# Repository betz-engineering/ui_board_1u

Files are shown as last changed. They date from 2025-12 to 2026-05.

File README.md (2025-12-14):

# ui_board_1u
A versatile user interface PCB, specifically designed for integration into the front-panel of a 1U height chassis.

__Featuring__

  * Rotary encoder
  * 2x RGB LEDs, brought to the front with light-pipes for mounting flexibility
  * 1x Tactile push button
  * 2.8" diagonal, 256 x 64 pixel OLED display with 16 shades (SSD1322)
  * All connected to a single 12 pin PMOD port

[__Schematic__](pics/ui_board_1u.pdf)

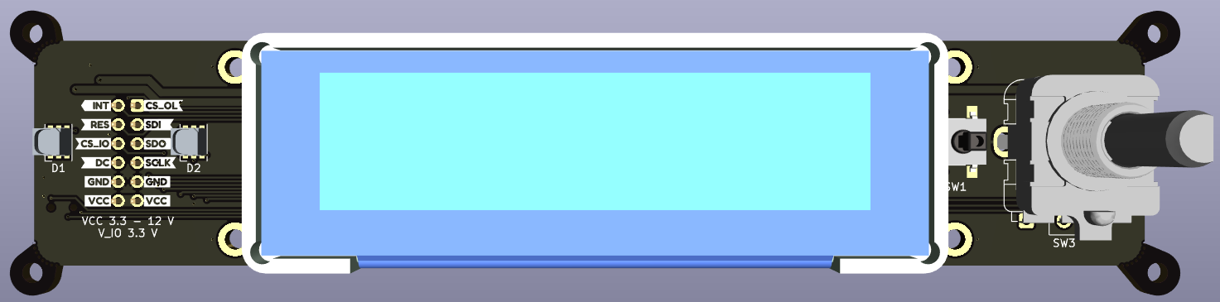
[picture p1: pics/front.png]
Front side render


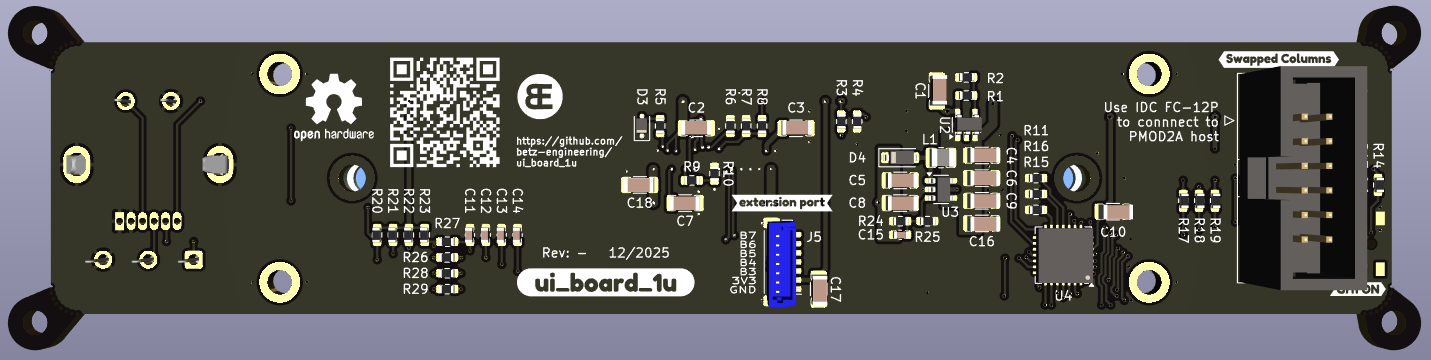
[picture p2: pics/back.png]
Back side render


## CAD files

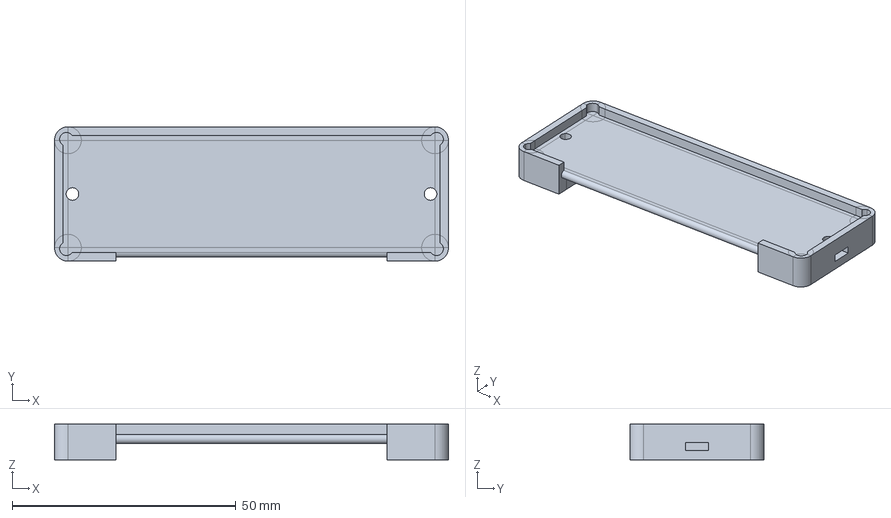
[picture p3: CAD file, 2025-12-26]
cad/step/oled_panel_frame.step
88.0 x 30.0 x 8.00 mm

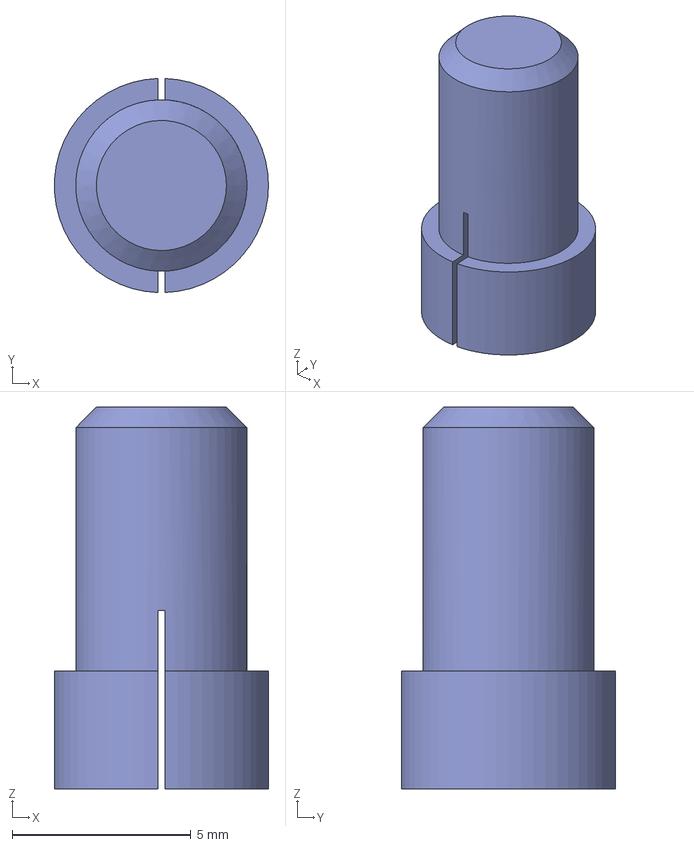
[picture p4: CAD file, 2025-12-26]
cad/step/button_cap.step
5.99 x 6.00 x 10.7 mm

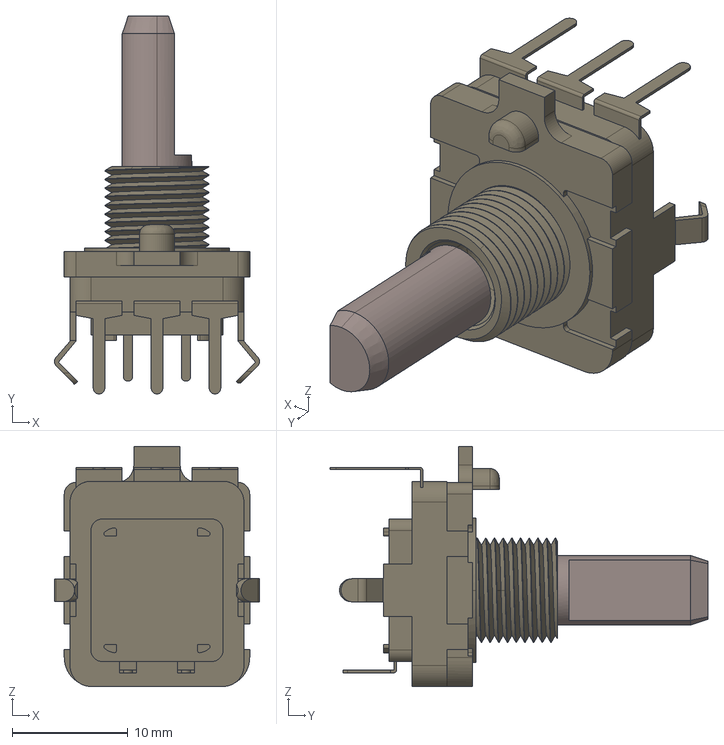
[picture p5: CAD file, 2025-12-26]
cad/step/PEC16-4X20F-SXXXX.stp
17.7 x 32.6 x 20.7 mm
PEC16-4X20F-SXXXX
PEC16-4X20F-SXXXX001

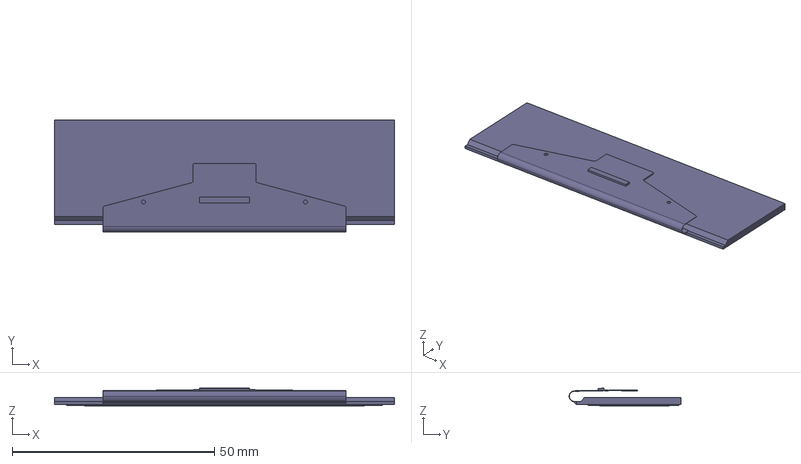
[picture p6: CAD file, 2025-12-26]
cad/step/oled_panel_2.8inch.step
84.0 x 27.6 x 4.35 mm
NHD-2.8-25664UCx008 x 2
Sketch

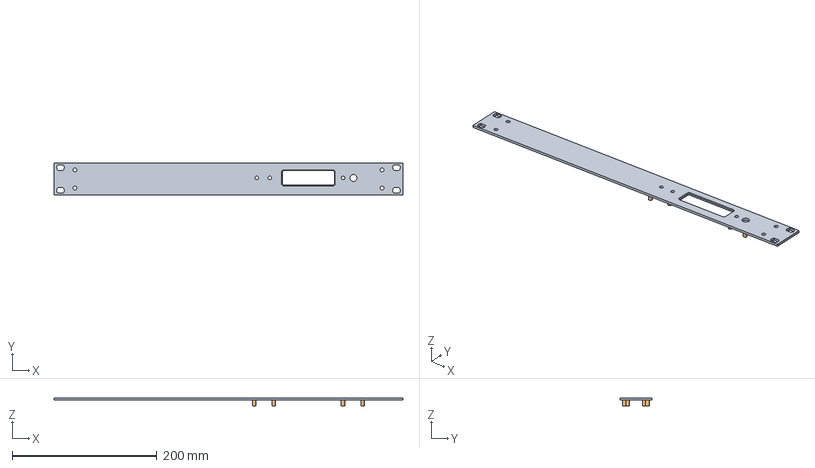
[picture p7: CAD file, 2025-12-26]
cad/step/example_panel_1U.stp
483.0 x 43.6 x 11.0 mm

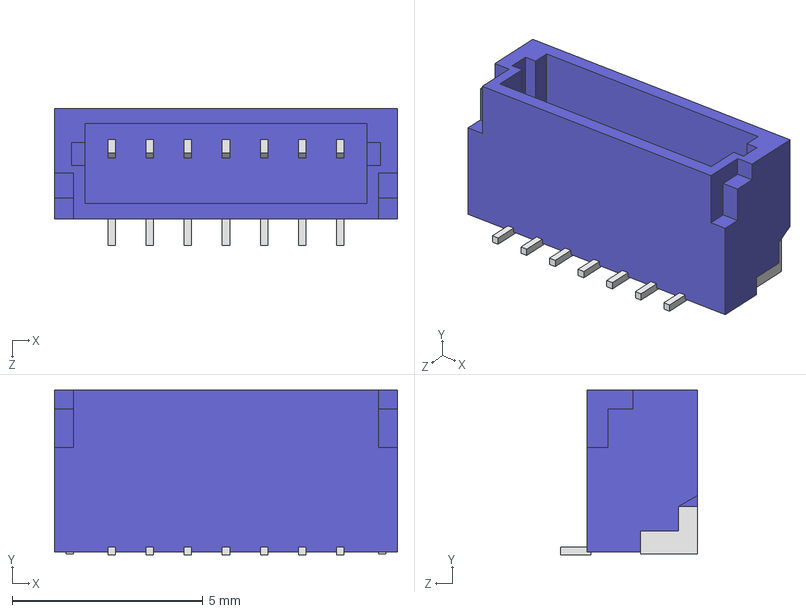
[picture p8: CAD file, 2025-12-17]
cad/step/BM07B-SRSS-TB.STEP
9.00 x 4.32 x 3.60 mm

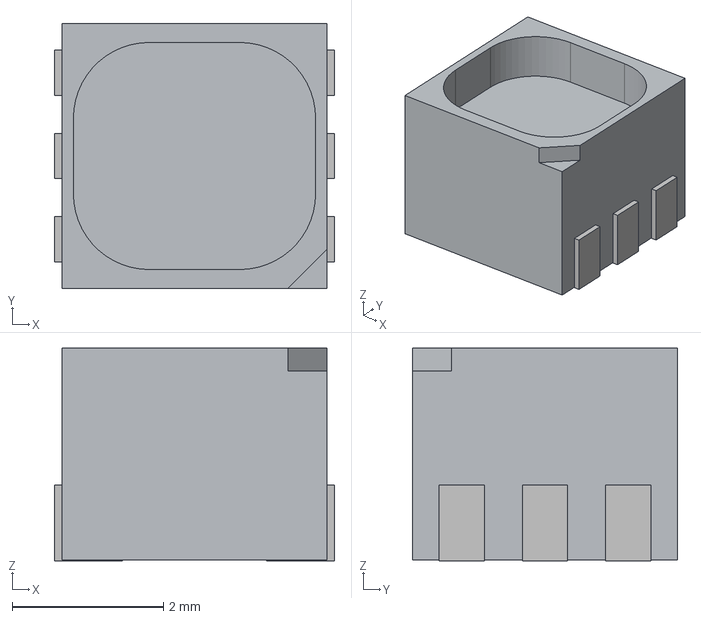
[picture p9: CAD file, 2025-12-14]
cad/step/RS-3535MWAR.step
3.70 x 3.50 x 2.81 mm

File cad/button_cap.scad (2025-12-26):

$fn = $preview ? 30 : 200;

include <helpers.scad>

gap = 0.2;

w_head = 2.4 + gap;
w_clip = w_head - 0.5;

h_clip = 1.0;  // height of the hook shaped clip
h_head = 1.8 + gap;  // height of the cube head of the button
h_stamp = h_clip + h_head;  // total height of the negative area

h_button = 8 + 7; // total height of the button measured from the _PCB_
h_cap = h_stamp + h_button - 7.3;
echo(h_cap);

module half_stamp() {
	polygon(points=[
		[0, 0],
		[-w_head / 2, 0],
		[-w_clip / 2, h_clip],
		[-w_head / 2, h_clip],
		[-w_head / 2, h_stamp],
		[0, h_stamp],
	]);
}

// half_stamp();

module stamp() {
	translate([0, w_head / 2, 0])
		rotate([90, 0, 0])
			linear_extrude(w_head)
				union() {
					half_stamp();
					mirror([1, 0, 0]) half_stamp();
				}
}

module cap(){
	difference() {
		union() {
			// Outer diameter of the cap (which needs to fit in the 5 mm hole of the FP)
			cylinder(h=h_cap, d=5 - gap);
			// larger diameter for the inside part
			cylinder(h=h_stamp + 8 - 7.3 - 2 * gap, d=6);
		}
		stamp();
		// the slot
		cube(size=[gap, 10, 10], center=true);
		// chamfer the edges on the top
		translate([0, 0, h_cap - 5.25])
			cone();
	}
}

module cone()
	rotate_extrude()
		translate([5 * sqrt(2), 0, 0])
			rotate([0, 0, 45])
				square([10, 10]);


// simulate the switch head
// translate([0, 0, 7.3 - 1.8])
// 	cube_(size=[2.4, 2.4, 1.8]);

echo("button z", -h_stamp + 7.3 + gap / 2);

intersection() {
	translate([0, 0, -h_stamp + 7.3 + gap / 2])
		!cap();
	translate([0, 50, 0])
		cube(size=[100, 100, 100], center=true);
}

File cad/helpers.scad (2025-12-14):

// centered on XY only
module cube_(size=[1, 1, 1])
	translate([-size[0] / 2, -size[1] / 2, 0])
		cube(size);

// centered on XY only
module roundedcubez(size = [1, 1, 1], radius = 0.5) {
	linear_extrude(height=size[2]) {
		square([size[0] - 2 * radius, size[1]], center=true);
		square([size[0], size[1] - 2 * radius], center=true);
		for (i=[-1, 1])
			for (j=[-1, 1])
				translate([i * (size[0] / 2 - radius), j * (size[1] / 2 - radius), 0])
					circle(r = radius);
	}
}

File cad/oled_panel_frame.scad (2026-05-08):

$fn = $preview ? 30 : 200;

include <helpers.scad>

w_panel = 84;
w_flex = 60;
h_panel = 25.8;
t_panel = 2.0;


shell_thickness = 2;

// space (wiggle room) between panel and frame around it
gap = 0.3;

// How far the bottom of the panel is lifted from the carrier PCB
h_offset = 5.7;
echo("h_offset: ", h_offset);

// Total height of the part
h_total = h_offset + t_panel + gap;
echo("h_total: ", h_total);

// The rounded lip part
d_lip = 2;
y_lip = 0;


module panel() {
	color("grey")
		translate([0, 1, (t_panel - 0.75) / 2])
			cube(size=[w_panel, h_panel - 2, t_panel - 0.75], center=true);
	color("lightgrey")
		translate([0, 0, t_panel - 0.75 / 2])
			cube(size=[w_panel, h_panel, 0.75], center=true);
	translate([0, -10 - h_panel / 2, 1.20])
		cube(size=[w_flex, 25, 0.1], center=true);
}


module oled_frame() {
	difference() {
		roundedcubez(size=[w_panel + shell_thickness * 2, 30, h_total], radius=3);

		// pocket for the display
		translate([0, 0, h_offset])
			cube_(size=[w_panel + gap, h_panel + gap, 10]);

		// Opening for the flex
		// remove the lip to shape it better
		translate([0, -10 - (h_panel + gap) / 2 - y_lip, 0])
			cube_(size=[w_flex + 2 * gap, 20, 10]);

		// Clear out the top
		translate([0, -25, h_offset])
			cube_(size=[w_flex + 2 * gap, 50, 10]);

		// Clear out the bottom
		cube(size=[w_flex + 2 * gap, 100, (h_offset - d_lip) * 2], center=true);

		// slots for M2.5 square nuts
		for (i=[-1, 1]) {
			translate([40 * i, 0, 3]) {
				translate([2 * i, 0, 0]){
					cube(size=[10, 5.1, 1.6], center=true);
				}
				translate([0, 0, -1])
					cylinder(h=10, d=2.8, center=true);
			}

			// Dog bones
			for (j=[-1, 1])
				translate([i * ((w_panel + gap) / 2 - 0.8), j * ((h_panel + gap) / 2 - 0.8), 5 + h_offset])
					cylinder(h=10, d=3, center=true);
		}
	}

	// The rounded lip
	translate([0, -(h_panel + gap) / 2 - y_lip, -d_lip/2 + h_offset]) {
		rotate([0, 90, 0])
			cylinder(h=w_flex + 2 * gap, d=d_lip, center=true);
	}

	// Square nut retainer
	for (i=[-1, 1])
		for (j=[-1, 1])
			translate([43.3 * i, j * 1.5, 3.88])
				rotate([0, -i * 15, 0])
					cube(size=[1.25, 0.6, 0.5], center=true);
}

// translate([0, 0, h_offset + gap])
// 	panel();

intersection() {
	union() {
		!oled_frame();
		// Square nut
		translate([40, 0, 2])
			cube_(size=[5.0, 5.0, 1.6]);
		// // Screw
		translate([40, 0, -1.6])
			cylinder(h=6, d=2.5);
	}
	// translate([0, 50, 0])
	// 	cube(size=[100, 100, 100], center=true);
}

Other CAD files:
cad/RS-3535MWAR.scad

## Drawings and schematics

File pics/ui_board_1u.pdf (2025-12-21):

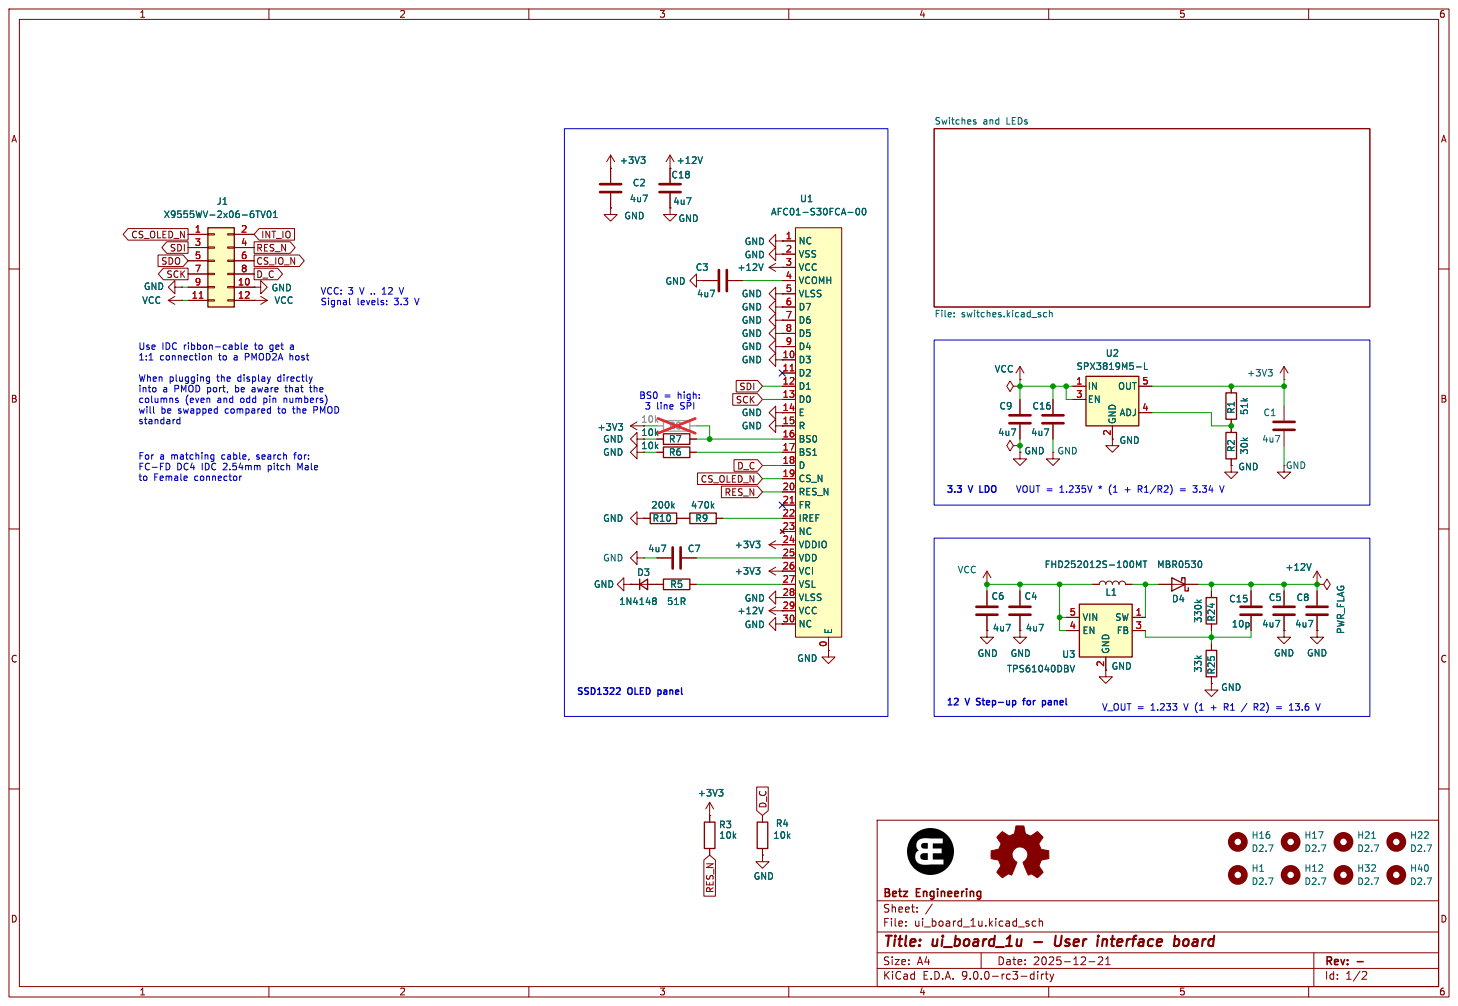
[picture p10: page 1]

10k GND GND GND GND GND GND GND GND

into a PMOD port, be aware that the

Id: 1/2 Title: ui_board_1u - User interface board

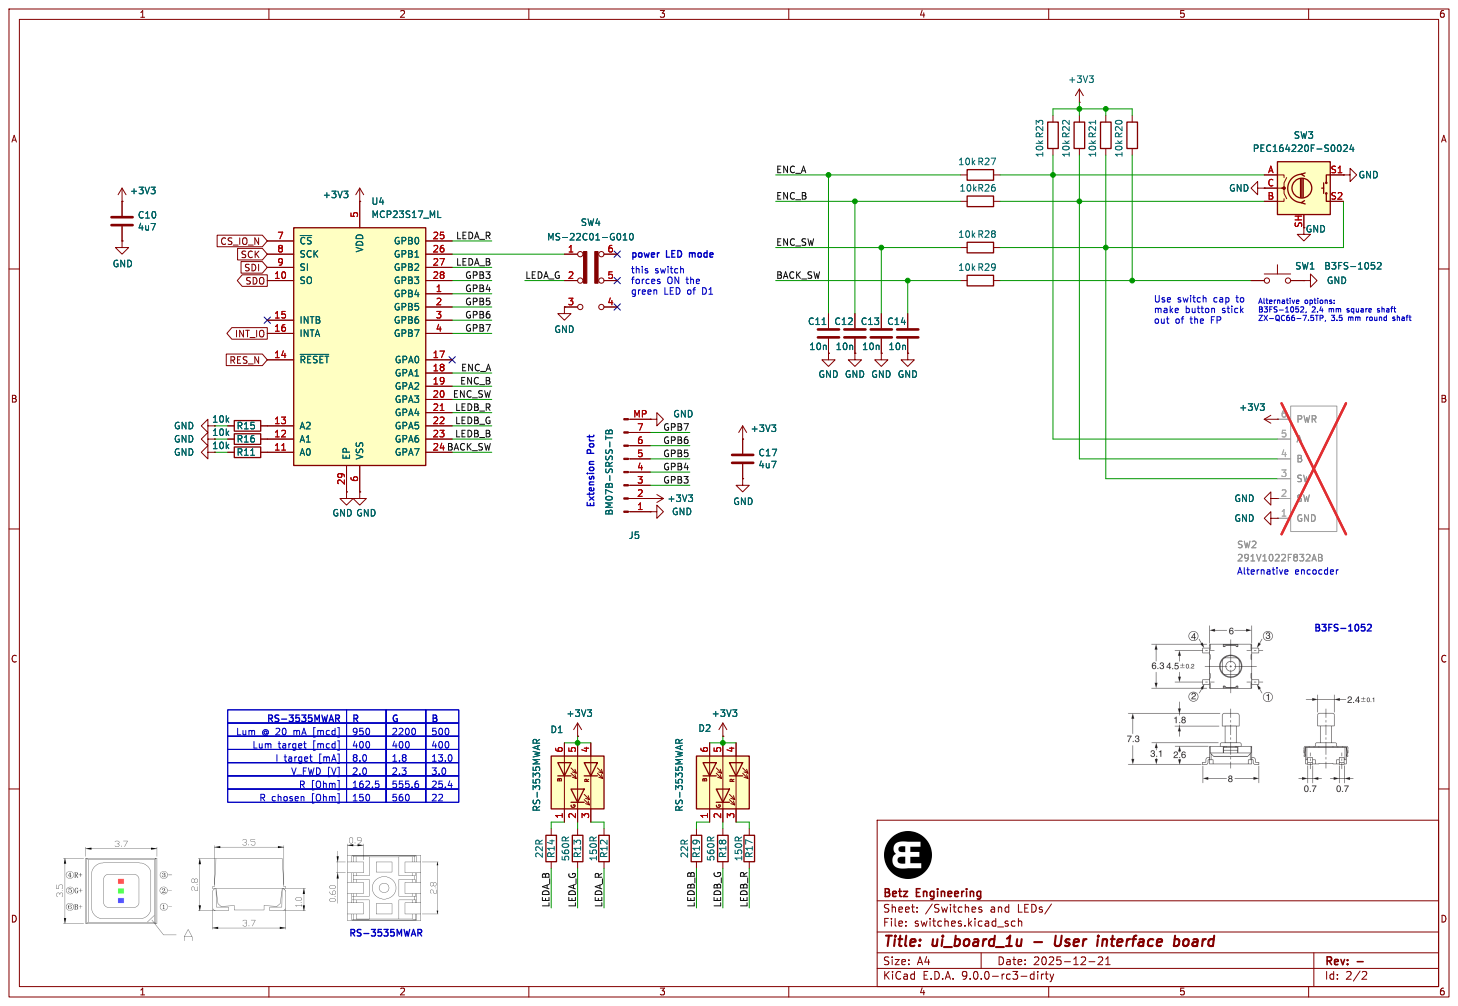
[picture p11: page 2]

6 GPB0 25 GPB1 26 GPB2 27 GPB3 28 GPB4 1 GPB5 2 GPB6 3 GPB7 4 GPA0 17 GPA1 18 GPA2 19 GPA3 20 GPA4 21 GPA5 22 GPA6 23 GPA7 24 GND GND
power LED mode Extension Port RS-3535MWAR

Id: 2/2 Title: ui_board_1u - User interface board

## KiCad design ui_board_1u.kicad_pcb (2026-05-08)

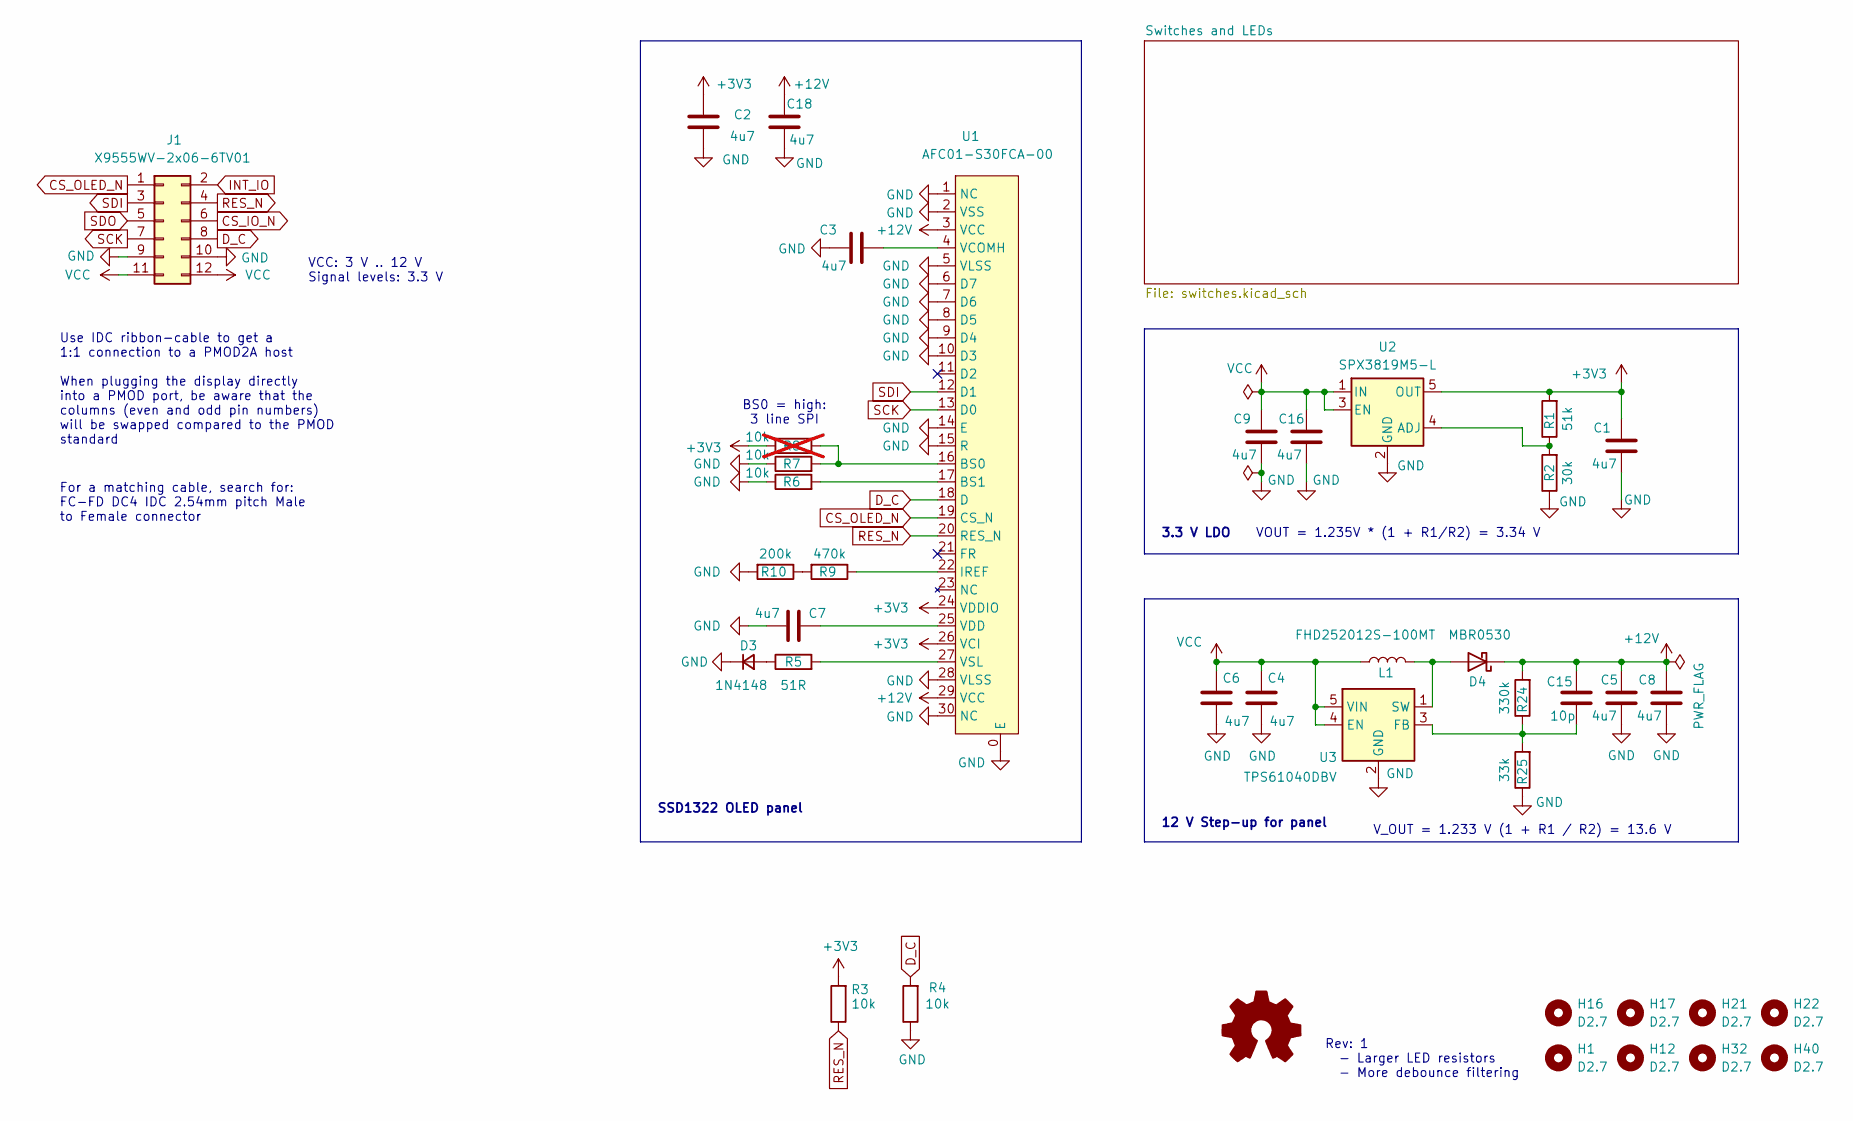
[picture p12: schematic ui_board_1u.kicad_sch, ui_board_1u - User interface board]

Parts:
C1, C2, C3, C4, C5, C6, C7, C8, C9, C16, C18: 4u7; C_1206_3216Metric
C15: 10p; C_0603_1608Metric
D3: 1N4148; D_SOD-323F
D4: MBR0530; D_SOD-123
H1, H12, H32, H40: D2.7; MountingHole_2.7mm_M2.5_ISO7380
H16, H17, H21, H22: D2.7; MountingHole_2.7mm_M2.5_ISO7380_Pad
J1: X9555WV-2x06-6TV01; IDC-Header_2x06_P2.54mm_Vertical
L1: FHD252012S-100MT; L_1008_2520Metric
R1: 51k; R_0603_1608Metric
R2: 30k; R_0603_1608Metric
R3, R4, R6, R7: 10k; R_0603_1608Metric
R5: 51R; R_0603_1608Metric
R8: 10k; R_0603_1608Metric; not fitted
R9: 470k; R_0603_1608Metric
R10: 200k; R_0603_1608Metric
R24: 330k; R_0603_1608Metric
R25: 33k; R_0603_1608Metric
U1: AFC01-S30FCA-00; oled_frame_2.8
U2: SPX3819M5-L; SOT-23-5; LCSC Part # C9056
U3: TPS61040DBV; SOT-23-5

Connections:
+3V3: C1.1, C2.1, R1.2, R3.2, R8.1, U1.24 (VDDIO), U1.26 (VCI), U2.5 (OUT); also elsewhere on the board
+12V: C5.1, C8.1, C15.1, C18.1, D4.1 (K), R24.2, U1.3 (VCC), U1.29 (VCC)
CS_IO_N: J1.6; also elsewhere on the board
CS_OLED_N: J1.1, U1.19 (CS_N)
D_C: J1.8, R4.2, U1.18 (D)
GND: C1.2, C2.2, C3.2, C4.2, C5.2, C6.2, C7.2, C8.2, C9.2, C16.2, C18.2, D3.1 (K), J1.9, J1.10, R2.1, R4.1, R6.1, R7.1, R10.2, R25.1, U1.0 (E), U1.1 (NC), U1.2 (VSS), U1.5 (VLSS), U1.6 (D7), U1.7 (D6), U1.8 (D5), U1.9 (D4), U1.10 (D3), U1.14 (E), U1.15 (R), U1.28 (VLSS), U1.30 (NC), U2.2 (GND), U3.2 (GND); also elsewhere on the board
INT_IO: J1.2; also elsewhere on the board
unnamed: D3.2 (A), R5.1
unnamed: D4.2 (A), L1.2, U3.1 (SW)
unnamed: R9.2, R10.1
unnamed: R7.2, R8.2, U1.16 (BS0)
unnamed: R6.2, U1.17 (BS1)
unnamed: R9.1, U1.22 (IREF)
unnamed: C3.1, U1.4 (VCOMH)
unnamed: C7.1, U1.25 (VDD)
unnamed: R5.2, U1.27 (VSL)
unnamed: R1.1, R2.2, U2.4 (ADJ)
unnamed: C15.2, R24.1, R25.2, U3.3 (FB)
RES_N: J1.4, R3.1, U1.20 (RES_N); also elsewhere on the board
SCK: J1.7, U1.13 (D0); also elsewhere on the board
SDI: J1.3, U1.12 (D1); also elsewhere on the board
SDO: J1.5; also elsewhere on the board
VCC: C4.1, C6.1, C9.1, C16.1, J1.11, J1.12, L1.1, U2.1 (IN), U2.3 (EN), U3.4 (EN), U3.5 (VIN)

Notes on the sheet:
12 V Step-up for panel
V_OUT = 1.233 V (1 + R1 / R2) = 13.6 V
Rev: 1 - Larger LED resistors - More debounce filtering
3.3 V LDO
Use IDC ribbon-cable to get a 1:1 connection to a PMOD2A host When plugging the display directly into a PMOD port, be aware that the columns (even and odd pin numbers) will be swapped compared to the PMOD standard
SSD1322 OLED panel
For a matching cable, search for: FC-FD DC4 IDC 2.54mm pitch Male to Female connector
BS0 = high: 3 line SPI
VOUT = 1.235V * (1 + R1/R2) = 3.34 V
VCC: 3 V .. 12 V Signal levels: 3.3 V

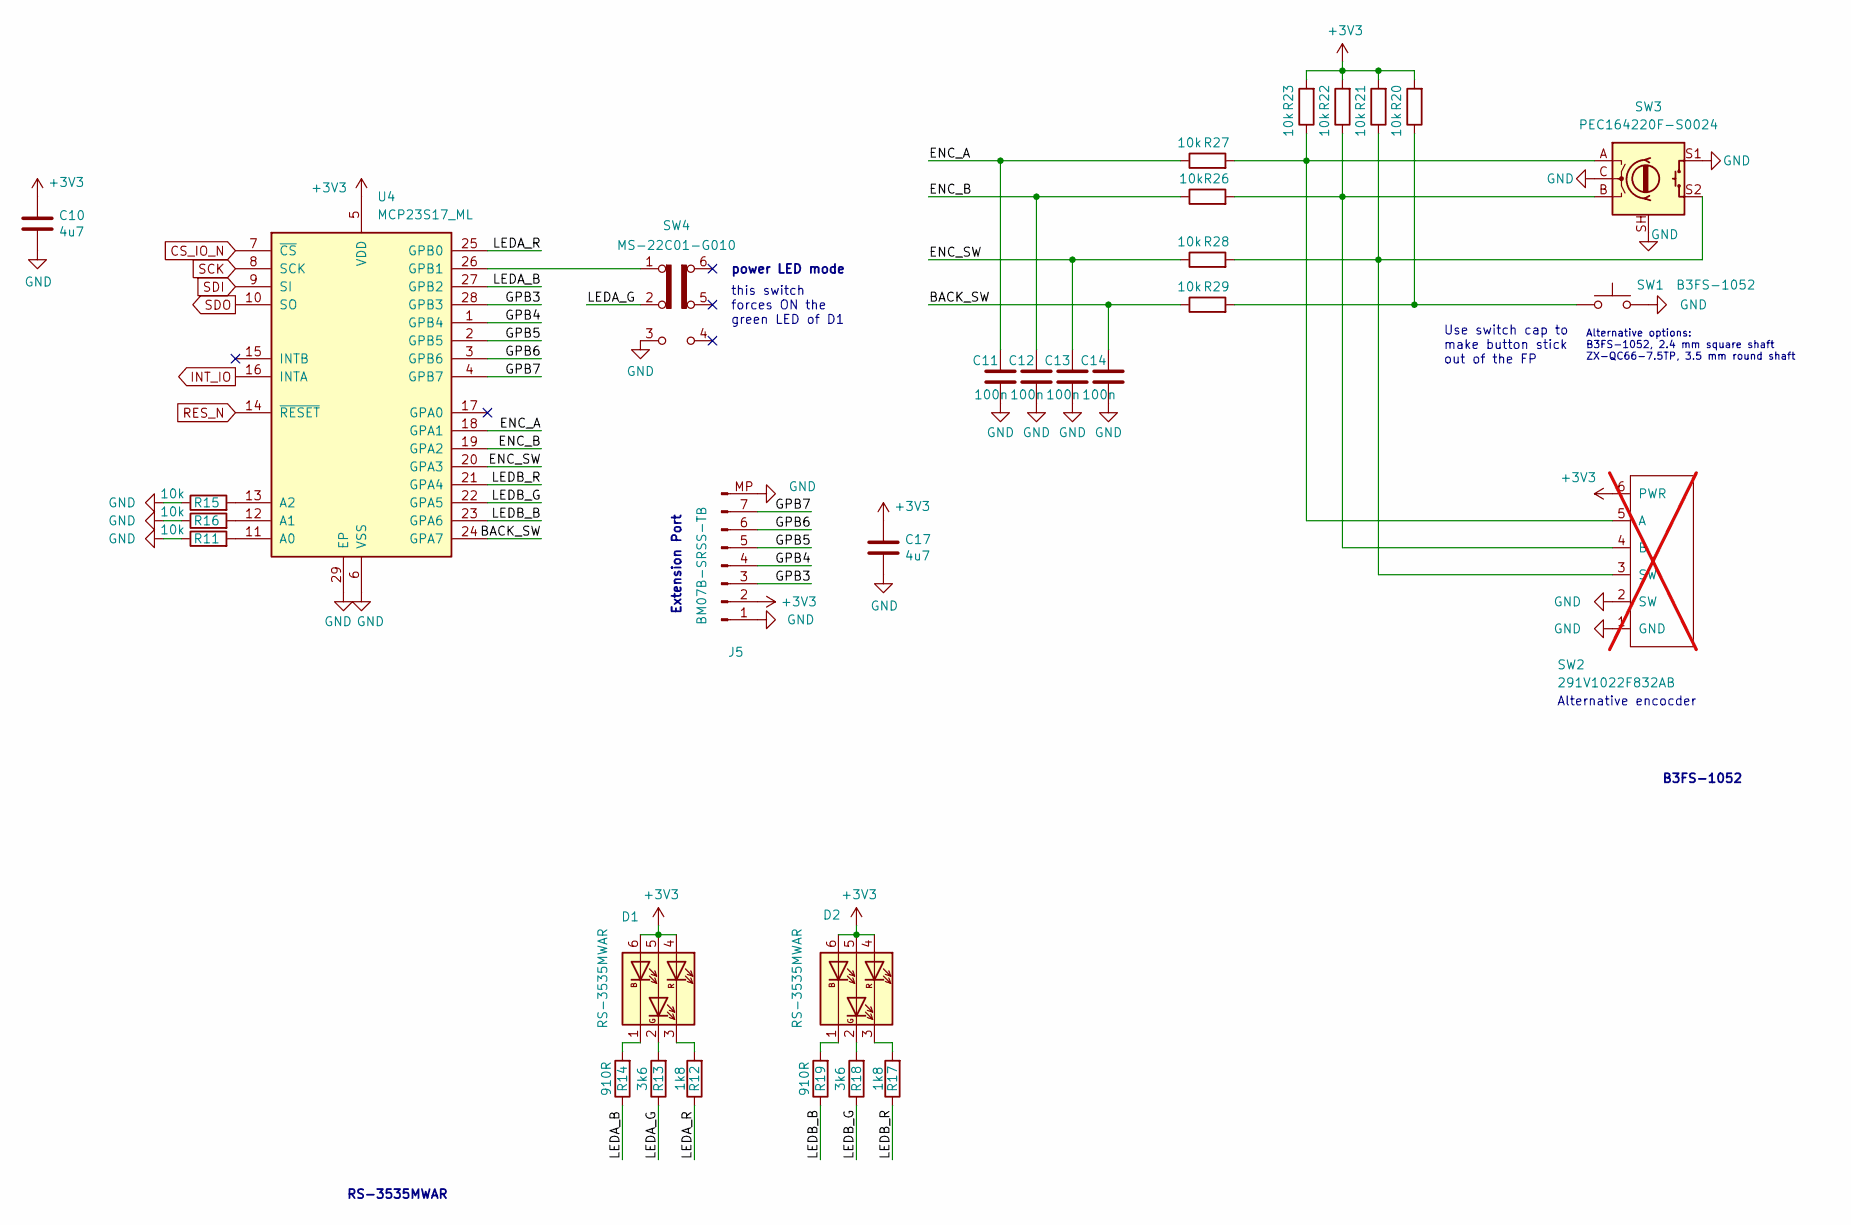
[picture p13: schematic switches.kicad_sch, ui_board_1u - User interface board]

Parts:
C10, C17: 4u7; C_1206_3216Metric
C11, C12, C13, C14: 100n; C_0603_1608Metric
D1, D2: RS-3535MWAR; LED_RGB_PLCC-6
J5: BM07B-SRSS-TB; JST_SH_BM07B-SRSS-TB_1x07-1MP_P1.00mm_Vertical; LCSC Part # C160393
R11, R15, R16, R20, R21, R22, R23, R26, R27, R28, R29: 10k; R_0603_1608Metric
R12, R17: 1k8; R_0603_1608Metric
R13, R18: 3k6; R_0603_1608Metric
R14, R19: 910R; R_0603_1608Metric
SW1: B3FS-1052; SW_SPST_Omron_B3FS-105xP
SW2: 291V1022F832AB; 291V1; digikey CT3044-ND; not fitted
SW3: PEC164220F-S0024; RotaryEncoder_Bourns_Vertical_PEC16-4xxxF-Sxxxx
SW4: MS-22C01-G010; MS-22C01
U4: MCP23S17_ML; QFN-28-1EP_6x6mm_P0.65mm_EP4.25x4.25mm

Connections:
+3V3: C10.1, C17.1, D1.4 (AR), D1.5 (AG), D1.6 (AB), D2.4 (AR), D2.5 (AG), D2.6 (AB), J5.2, R20.2, R21.2, R22.2, R23.2, SW2.6 (PWR), U4.5 (VDD); also elsewhere on the board
/Switches and LEDs/BACK_SW: C14.1, R29.1, U4.24 (GPA7)
/Switches and LEDs/ENC_A: C11.1, R27.1, U4.18 (GPA1)
/Switches and LEDs/ENC_B: C12.1, R26.1, U4.19 (GPA2)
/Switches and LEDs/ENC_SW: C13.1, R28.1, U4.20 (GPA3)
/Switches and LEDs/GPB3: J5.3, U4.28 (GPB3)
/Switches and LEDs/GPB4: J5.4, U4.1 (GPB4)
/Switches and LEDs/GPB5: J5.5, U4.2 (GPB5)
/Switches and LEDs/GPB6: J5.6, U4.3 (GPB6)
/Switches and LEDs/GPB7: J5.7, U4.4 (GPB7)
/Switches and LEDs/LEDA_B: R14.1, U4.27 (GPB2)
/Switches and LEDs/LEDA_G: R13.1, SW4.2 (B)
/Switches and LEDs/LEDA_R: R12.1, U4.25 (GPB0)
/Switches and LEDs/LEDB_B: R19.1, U4.23 (GPA6)
/Switches and LEDs/LEDB_G: R18.1, U4.22 (GPA5)
/Switches and LEDs/LEDB_R: R17.1, U4.21 (GPA4)
CS_IO_N: U4.7 (~CS); also elsewhere on the board
GND: C10.2, C11.2, C12.2, C13.2, C14.2, C17.2, J5.1, J5.MP, R11.1, R15.1, R16.1, SW1.2, SW2.1 (GND), SW2.2 (SW), SW3.C, SW3.S1, SW3.SH, SW4.3 (C), U4.6 (VSS), U4.29 (EP); also elsewhere on the board
INT_IO: U4.16 (INTA); also elsewhere on the board
unnamed: D1.1 (KB), R14.2
unnamed: D1.2 (KG), R13.2
unnamed: D1.3 (KR), R12.2
unnamed: D2.1 (KB), R19.2
unnamed: D2.2 (KG), R18.2
unnamed: D2.3 (KR), R17.2
unnamed: R20.1, R29.2, SW1.1
unnamed: R21.1, R28.2, SW2.3 (SW), SW3.S2
unnamed: R23.1, R27.2, SW2.5 (A), SW3.A
unnamed: R22.1, R26.2, SW2.4 (B), SW3.B
unnamed: R11.2, U4.11 (A0)
unnamed: R16.2, U4.12 (A1)
unnamed: R15.2, U4.13 (A2)
unnamed: SW4.1 (A), U4.26 (GPB1)
RES_N: U4.14 (~RESET); also elsewhere on the board
SCK: U4.8 (SCK); also elsewhere on the board
SDI: U4.9 (SI); also elsewhere on the board
SDO: U4.10 (SO); also elsewhere on the board

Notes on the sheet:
B3FS-1052
RS-3535MWAR
Extension Port
this switch forces ON the green LED of D1
Alternative options: B3FS-1052, 2.4 mm square shaft ZX-QC66-7.5TP, 3.5 mm round shaft
Use switch cap to make button stick out of the FP
power LED mode
Alternative encocder

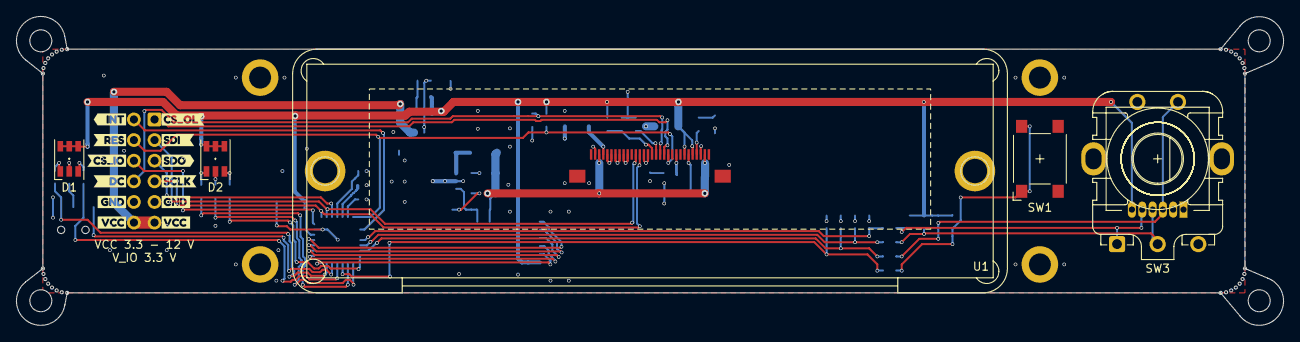
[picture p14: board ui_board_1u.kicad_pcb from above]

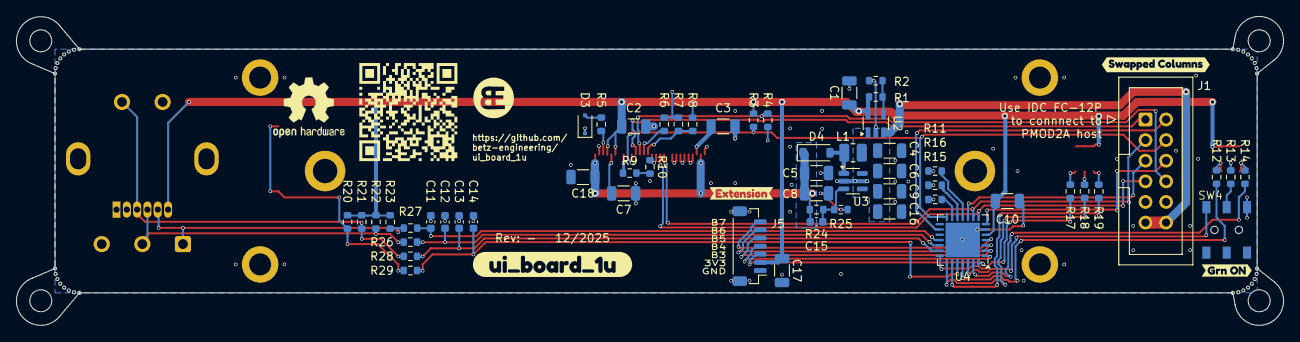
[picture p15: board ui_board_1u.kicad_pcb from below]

Board: 2 copper layers, 156.0 x 38.0 mm, 121 parts (63 on the bottom side), 52 nets.

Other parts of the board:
G0, G1: LOGO
G2: OSHW-Logo2_9.8x8mm_SilkScreen
H2, H3, H4, H5, H6, H7, H8, H9, H10, H11, H13, H14, H15, H18, H19, H20, H23, H24, H25, H26, H27, H28, H29, H30, H31, H33, H34, H35, H36, H37, H38, H39: mouse_bite
kibuzzard-1: G***; kibuzzard-693D4C30
kibuzzard-2: G***; kibuzzard-6940589C
kibuzzard-3: G***; kibuzzard-693D4C36
kibuzzard-4: G***; kibuzzard-69405870
kibuzzard-5: G***; kibuzzard-69405890
kibuzzard-6: G***; kibuzzard-6940587B
kibuzzard-7: G***; kibuzzard-693D4C42
kibuzzard-8: G***; kibuzzard-693D4BEE
kibuzzard-9: G***; kibuzzard-693D4C48
kibuzzard-10: G***; kibuzzard-693D4BE6
kibuzzard-11: G***; kibuzzard-693D4C4F
kibuzzard-12: G***; kibuzzard-693D4BDF
kibuzzard-13: G***; kibuzzard-693D4AF8
kibuzzard-14: G***; kibuzzard-693EBA51
kibuzzard-15: G***; kibuzzard-693D4DAF
kibuzzard-69483936: G***; kibuzzard-69483936

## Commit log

2025-12-14 fix 3D models
    [PEC16-4X20F-SXXXX.stp, RS-3535MWAR.step, example_front_panel_2u.step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]
2025-12-14 add QR code to silkscreen, add render images
    [ui_board_1u.kicad_pcb]
2025-12-14 optimize component values for easier production
    [switches.kicad_sch, ui_board_1u.kicad_pcb, ui_board_1u.kicad_sch]
2025-12-14 add Schematic .pdf
    [switches.kicad_sch]
2025-12-14 update Schematic sheet
    [switches.kicad_sch, ui_board_1u.kicad_sch]
2025-12-14 oled_panel_frame.scad: remove redundant code
    [oled_panel_frame.scad]
2025-12-15 rename POCI and PICO signals to SDO and SDI
    according to the OSHWA recommendation
    https://oshwa.org/resources/a-resolution-to-redefine-spi-signal-names/
    [switches.kicad_sch, ui_board_1u.kicad_pcb, ui_board_1u.kicad_sch]
2025-12-15 fix / ignore all remaining DRC errors
    [ui_board_1u.kicad_pcb]
2025-12-15 geographical re-annotate
    [switches.kicad_sch, ui_board_1u.kicad_pcb, ui_board_1u.kicad_sch]
2025-12-15 update schematic .pdf and pictures
    [ui_board_1u.kicad_pcb]
2025-12-17 review OLED pinout, add 2 GND pins
    [switches.kicad_sch, ui_board_1u.kicad_pcb, ui_board_1u.kicad_sch]
2025-12-17 add extension board connector
    [BM07B-SRSS-TB.STEP, switches.kicad_sch, ui_board_1u.kicad_pcb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]
2025-12-17 fix typo in schematic
    [switches.kicad_sch, ui_board_1u.kicad_sch]
2025-12-17 fix some more typos in the schematic
    [switches.kicad_sch, ui_board_1u.kicad_sch]
2025-12-21 add button cap for Omron button
    [button_cap.scad, oled_panel_frame.scad]
2025-12-21 Make button cap longer. Update 3D models
    [button_cap.scad, button_cap.step, oled_panel_frame.scad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]
2025-12-21 fine tune ext. con position and silk screen
    rev - ready to order
    [switches.kicad_sch, ui_board_1u.kicad_pcb, ui_board_1u.kicad_sch]
2025-12-23 add drawing for front-panel cut-outs in User.Comments and Eco1 layers
    [ui_board_1u.kicad_pcb]
2025-12-23 button-cap: change outer diameter from 5.0 to 4.6 mm
    [button_cap.scad]
2025-12-26 cutout drawing: update, snap to grid
    also add exmaple front panel designer file
    [example_panel_1U.stp, ui_board_1u.kicad_pcb]
2025-12-26 update most of the .step files
    * button_cap and oled_frame: update ot the final dimensions
    * oled_panel: add color to the active area
    * add example front-panel .step
    [PEC16-4X20F-SXXXX.stp, button_cap.scad, button_cap.step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]
2025-12-26 remove unused 2U example panel
    [example_front_panel_2u.step]
2025-12-27 move step file to website
    [ui_board_1u.step]
2026-05-08 oled_panel_frame: add square nut retainer
    [oled_panel_frame.scad]
2026-05-08 rev1, port to kicad 10
    * revise LED resistor values. They were much to bright.
    * Change debouncing filter cap. from 10 nF to 100 nF
    * change to kicad 10
    [switches.kicad_sch, ui_board_1u.kicad_sch]
2026-05-08 PCB: sync with schematic. Upgrade to kicad 10
    [ui_board_1u.kicad_pcb]
